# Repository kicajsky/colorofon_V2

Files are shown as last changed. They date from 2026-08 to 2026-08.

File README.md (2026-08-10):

# colorofon_V2
3-Channel Analog Colorofon

An analog color organ based on the MCP6002 operational amplifier, designed to visualize an audio signal through three independent frequency channels: Low, Mid, and High.

The circuit operates from a single 12 V supply and uses a 6 V virtual ground for analog signal processing. Each frequency channel independently processes the audio signal and provides a dedicated output for controlling external lighting.

3 frequency channels: Low / Mid / High
Fully analog signal processing
MCP6002 operational amplifier
12 V single-supply operation
6 V virtual ground
Audio signal input
Independent output for each channel
Schematic and PCB design included

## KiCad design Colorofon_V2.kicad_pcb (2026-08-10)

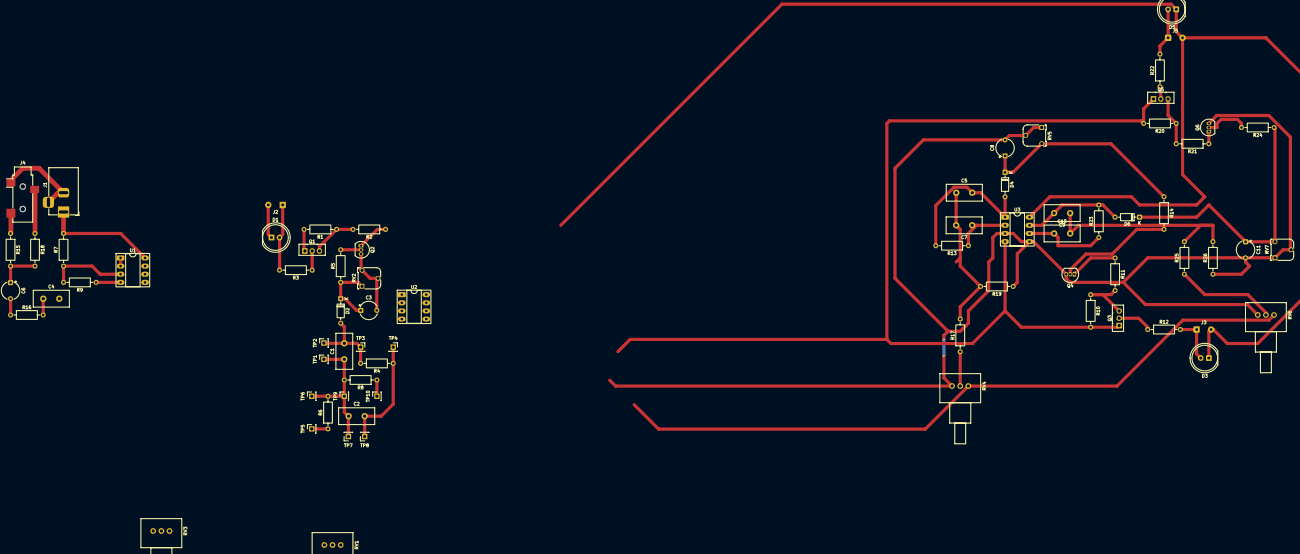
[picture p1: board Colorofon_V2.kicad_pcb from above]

Board: 2 copper layers, 74 parts (0 on the bottom side), 40 nets.

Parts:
C1, C2: 18n; C_Disc_D11.0mm_W5.0mm_P5.00mm
C3, C8, C11: 4.7u; CP_Radial_Tantal_D5.5mm_P5.00mm
C4: 100p; C_Disc_D11.0mm_W5.0mm_P5.00mm
C5, C7, C9, C10: 47n; C_Disc_D11.0mm_W5.0mm_P5.00mm
C6: 10u; CP_Radial_Tantal_D5.5mm_P5.00mm
D1, D3, D5: LED_Series; LED_D8.0mm
D2, D4, D6: 1N4148; D_DO-35_SOD27_P7.62mm_Horizontal
J1: Barrel_Jack_MountingPin; BarrelJack_Horizontal
J2, J3, J5: Conn_01x02_Socket; SolderWire-0.25sqmm_1x02_P4.5mm_D0.65mm_OD2mm
J4: AudioJack3; Jack_3.5mm_CUI_SJ-3523-SMT_Horizontal
Q1, Q3, Q5: BD140; TO-126-3_Vertical
Q2, Q4, Q6: BC547; TO-92_Inline
R1, R7, R8, R9, R10, R19, R20, R26: 10k; R_Axial_DIN0207_L6.3mm_D2.5mm_P10.16mm_Horizontal
R2, R11, R21: 100; R_Axial_DIN0207_L6.3mm_D2.5mm_P10.16mm_Horizontal
R3, R12, R22: 560; R_Axial_DIN0207_L6.3mm_D2.5mm_P10.16mm_Horizontal
R4: 351k; R_Axial_DIN0207_L6.3mm_D2.5mm_P10.16mm_Horizontal
R5, R14, R17, R24, R25: 5.6k; R_Axial_DIN0207_L6.3mm_D2.5mm_P10.16mm_Horizontal
R6: 88k; R_Axial_DIN0207_L6.3mm_D2.5mm_P10.16mm_Horizontal
R13, R23: 330k; R_Axial_DIN0207_L6.3mm_D2.5mm_P10.16mm_Horizontal
R15, R16, R18: 5.1k; R_Axial_DIN0207_L6.3mm_D2.5mm_P10.16mm_Horizontal
RV1, RV3, RV4, RV6: 100k; Potentiometer_Vishay_148-149_Single_Horizontal
RV2, RV5, RV7: 10k; Potentiometer_Runtron_RM-065_Vertical
TP1, TP2, TP3, TP4, TP5, TP6, TP7, TP8, TP9, TP10: TestPoint_Alt; PinSocket_1x01_P2.54mm_Vertical
U1: LM358; DIP-8_W7.62mm_Socket_LongPads
U2, U3: MCP6002-xP; DIP-8_W7.62mm_Socket_LongPads

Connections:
+12V: J1.1, Q1.1 (E), Q3.1 (E), Q5.1 (E), R1.2, R7.2, R10.2, R20.2, U1.8 (V+), U2.4 (V-), U3.4 (V-)
/Vref: C3.2, C8.2, C11.2, Q2.3 (E), Q4.3 (E), Q6.3 (E), R8.1, R19.1, R26.1, RV1.1, RV2.1, RV2.2, RV4.1, RV5.1, RV5.2, RV6.1, RV7.1, RV7.2, TP10.1 (1_1), U1.1, U1.2 (-), U2.3 (+), U2.5 (+), U3.3 (+), U3.5 (+)
GND: D1.1 (K), D3.1 (K), D5.1 (K), J1.2, J1.MP (MountPin_MP), J2.2, J3.2, J4.S, J5.2, R9.1, U1.4 (V-), U2.8 (V+), U3.8 (V+)
unnamed: C1.1, C2.2, R6.2, R8.2, TP1.1 (1_1), TP6.1 (1_1), TP7.1 (1_1), TP9.1 (1_1)
unnamed: C4.2, RV1.3, RV3.1, RV3.2, RV4.3, RV6.3, U2.1
unnamed: C5.1, C7.2, R17.2, R19.2
unnamed: C6.1, R15.2, R18.2
unnamed: C6.2, R16.1
unnamed: C9.1, C10.2, R25.2, R26.2
unnamed: D1.2 (A), J2.1, R3.2
unnamed: C1.2, D2.2 (A), R4.2, TP2.1 (1_1), TP3.1 (1_1), U2.7
unnamed: C3.1, D2.1 (K), R5.1, RV2.3
unnamed: D3.2 (A), J3.1, R12.2
unnamed: C5.2, D4.2 (A), R13.2, U3.1
unnamed: C8.1, D4.1 (K), R14.1, RV5.3
unnamed: D5.2 (A), J5.1, R22.2
unnamed: C9.2, D6.2 (A), R23.2, U3.7
unnamed: C11.1, D6.1 (K), R24.1, RV7.3
unnamed: J4.R, R18.1
unnamed: J4.T, R15.1
unnamed: Q1.3 (B), R1.1, R2.2
unnamed: Q1.2 (C), R3.1
unnamed: Q2.2 (B), R5.2
unnamed: Q2.1 (C), R2.1
unnamed: Q3.3 (B), R10.1, R11.2
unnamed: Q3.2 (C), R12.1
unnamed: Q4.2 (B), R14.2
unnamed: Q4.1 (C), R11.1
unnamed: Q5.3 (B), R20.1, R21.2
unnamed: Q5.2 (C), R22.1
unnamed: Q6.2 (B), R24.2
unnamed: Q6.1 (C), R21.1
unnamed: R6.1, RV1.2, TP5.1 (1_1)
unnamed: R17.1, RV4.2
unnamed: R25.1, RV6.2
unnamed: R7.1, R9.2, U1.3 (+)
unnamed: C4.1, R16.2, RV3.3, U2.2 (-)
unnamed: C2.1, R4.1, TP4.1 (1_1), TP8.1 (1_1), U2.6 (-)
unnamed: C7.1, R13.1, U3.2 (-)
unnamed: C10.1, R23.1, U3.6 (-)
